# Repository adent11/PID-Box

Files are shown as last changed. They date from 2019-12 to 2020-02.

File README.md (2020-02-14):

# PID-Box Project <!--Temporary Title-->
The goal of the PID box project is to control the speed of a motor using a photinterrupter and PID.
# Project Timeline

|Week|Date| Planned Milestones|Actual Progress|
|----| -- | --- |---|
|1|10/28/19|Design mount for the motor, and the wheel|Designed mount for the motor, the wheel, and a simple t-slot wall|
|2|11/6/19|Design one wall assembly of motor, wheel, and <br/>photointerrupter|Made assembly with the motor, photointerrupter, LCD, some indicator LEDs, and the potentiometer|
|3|11/11/19|Finish designing the box, add in LCD, LED indicators,<br/> switches, battery pack, and potentiometer|Added switches, battery pack, and arduino; 3d printed motor mount|
|4|11/18/19|Add arduino, start assembling box|Started assembling, made fritzing diagram|
|5|12/2/19|Wire everything and get test code working|Mounted all but motor, due to its tendancy to attach crooked, started wiring|
|6|12/9/19|RPM code|Soldered wires to all of the components, wired all components, assembled box|
|7|1/6/20|PID code|Tested all components, started rpm code, |
|8|1/13/20|Non-PID code|Finished rpm code, started non-PID control code|
|9|1/22/20 |Wrap up loose ends|Finished non-PID control code, wrote PID code, started tuning PID variables|
|10|1/27/20|Delay compensation|Continued tuning PID constants, worked on problem with rpm accuracy|
|11|2/3/20|Delay compensation|Recut wheel, retuned PID constants|
|12|2/10/20|Delay compensation|Finalized code, finished readme|

# The Process
<details><summary><b>Pre-project Planning</b></summary>
<p>
I didn't do a lot of sketching or drawing out plans, so most of my project planning was done in either Solidworks or Arduino, starting with smaller assemblies or simple test codes to gain the understanding of how the project works. I did however spend a while before actually starting the project trying to understand how PID control works.
</p>
</details>

<details><summary><b>Week 1</b></summary>
<p>
  
* Designed mount for motor
* On the motor mount I had some trouble getting the screws to be in a place where I can screw all of them in, so I extended the part that attaches to the box
* Designed wheel 
<br/>
 <br/>
</p>
</details>

<details><summary><b>Week 2</b></summary>
<p>
  
* Made sub-assembly of the motor, wheel, and photointerrupter

<br/>


* Added a row of LEDs that will show the speed

<br/> 
</p>
</details>

<details><summary><b>Week 3</b></summary>
<p>
  
* Added in the rest of the components
* 3d printed the motor mount
* Made drawing of all PID box walls

<br/> 
</p>
</details>
  
<details><summary><b>Week 4</b></summary>
<p>
  
* Laser cut all walls
* Drilled to fix some holes that were the wrong size
* Recut a wall to have my name, labels for the switches, and some holes that should have been there
* Started making fritzing diagram
</p>
</details>

<details><summary><b>Week 5</b></summary>
<p>
  
* Got potentiometer and motor control working with test code
* Broke the wheel trying to put it on
* Made the hole in the wheel slightly wider and recut
* Having trouble attaching the motor and wheel straight
</p>
</details>
  
<details><summary><b>Week 6</b></summary>
<p>

* Soldered wires to all components
* Finished assembling box
* One problem that I faced this week was that all of my wiring had to fit into a relatively small space, so it was tedious and took a long time to wire <br/>
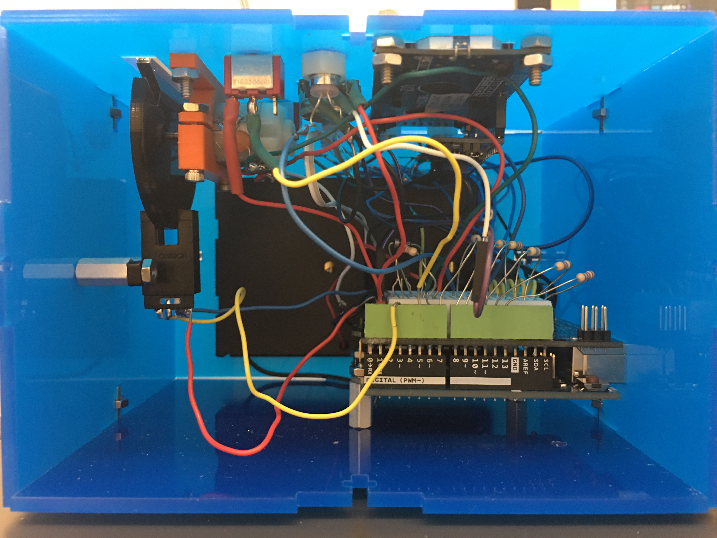
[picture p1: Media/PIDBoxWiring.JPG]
 <br/>
</p>
</details>

<details><summary><b>Week 7</b></summary>
<p>
  
* Tested all components
* I forgot to add a resistor to ground on the mode switch, so I had to solder that on
* Wrote rpm code

``` c++
int calcRPM()
{
  int rpm;
  rpm = interruptCount * (60000 / rpmCalcDelay) / 12; //Calculates rpm, interrupts times calculations per second divided by 
  return rpm;                                         //the number of interrupts per rotation
}
```
</p>
</details>

<details><summary><b>Week 8</b></summary>
<p>
  
* Finished and tested rpm code
* Started non-PID motor control code
</p>
</details>

<details><summary><b>Week 9</b></summary>
<p>
  
* Finished non-PID motor control code
* Finished PID control code
* Started tuning PID variables
</p>
</details>

<details><summary><b>Week 10</b></summary>
<p>
  
* Continued tuning PID constants
* Came across problem with RPM accuracy due to only having one hole cut in my wheel
</p>
</details>

<details><summary><b>Week 11</b></summary>
<p>
  
* Redesigned the wheel to have six holes instead of one for greater accuracy
* Retuned PID constants </br>
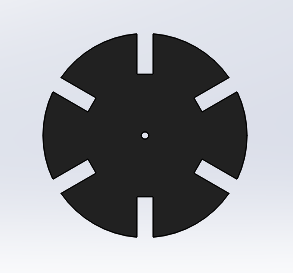
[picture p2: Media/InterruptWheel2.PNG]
 </br>
</p>
</details>

<details><summary><b>Week 12</b></summary>
<p>
  
* Finalized code
* Wrap up loose ends such as git
* Made this lovely readme
* Commented code
* Took videos, pictures, and screenshots
</p>
</details>
 
# The Finished Product

### Materials List
* LCD Screen
* LCD Backpack
* Photinterrupter
* 2 Switches
* 10k Potentiometer
* 6 AA Battery Pack
* DC Motor
* 8 220Ω Resistors
* 6 Red LEDs
* 1 Green LED
* Arduino Uno
* Prototyping Shield <br/>
* Box
* Wheel
* Motor Mount

### Wiring
The wiring for the PID Box was fairly straightforward, however having so many LEDs complicated my wiring slightly. I saved some space by soldering the ground legs of all of the LEDs together, and I used a breadboard in order to avoid having to solder resistors on to each LED. The first time I put it together, I forgot to ground the mode switch, so I had to reopen it and solder on the resistor. The only other complex wiring was that of the motor, but I already had that from the motor assignment, so all I had to do was copy it.
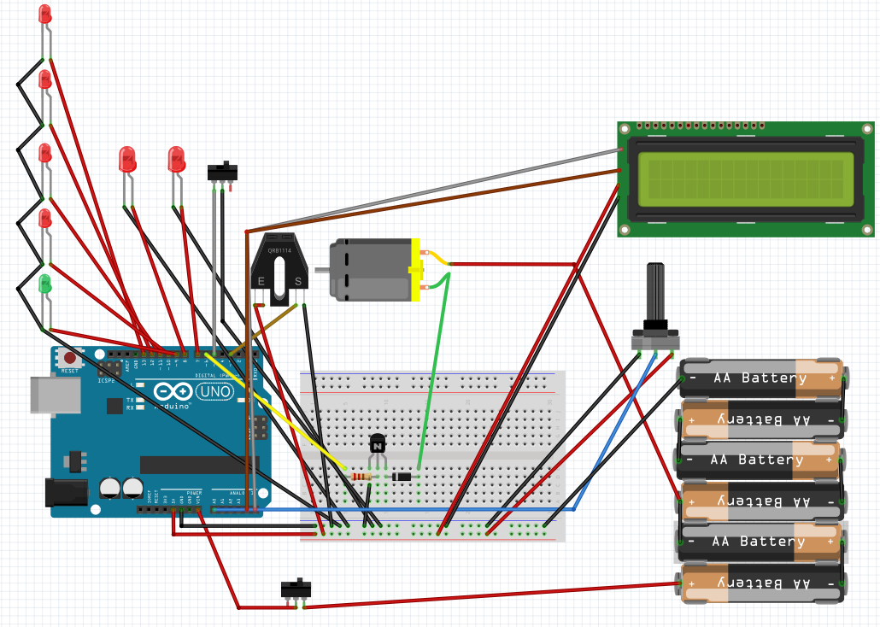
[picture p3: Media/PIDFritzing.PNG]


### The Box
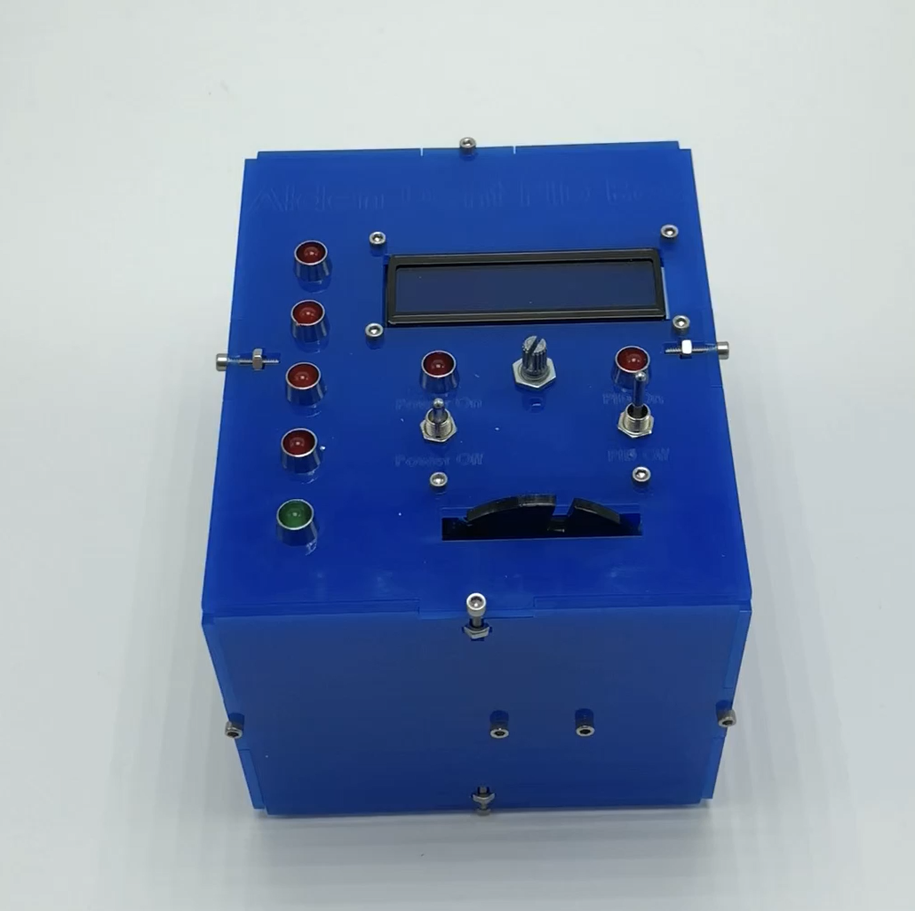
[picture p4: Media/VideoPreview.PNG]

<sup><a href="https://www.youtube.com/watch?v=RjP5sMNfZZY&feature=youtu.be" target="_blank">The PID Box in action</a></sup>

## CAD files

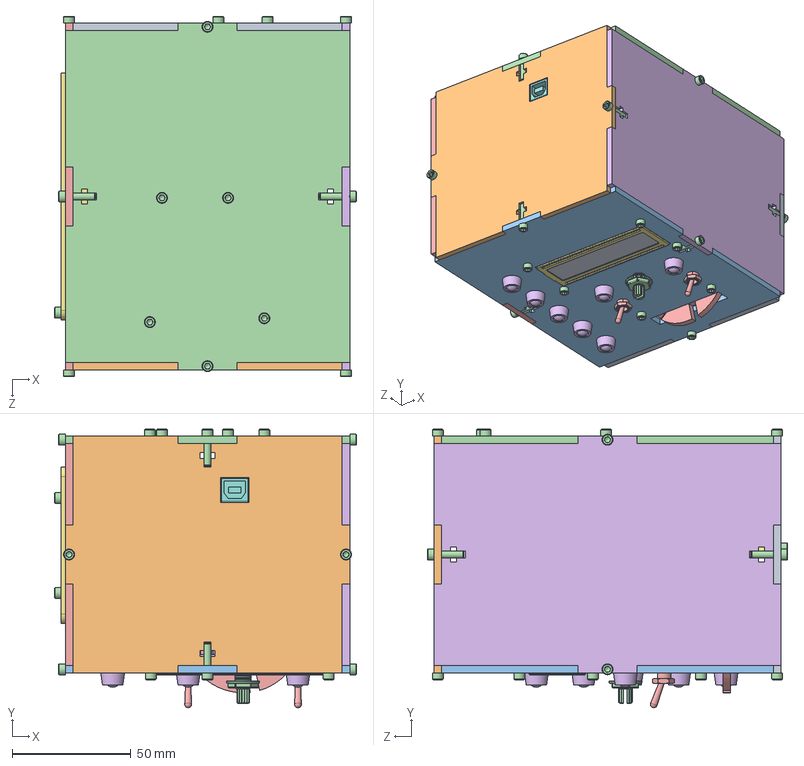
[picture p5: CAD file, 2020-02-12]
Solidworks/PIDBoxAssem.SLDASM
127.4 x 117.5 x 152.0 mm
PIDBoxFrontWall
PIDBoxBackWall
PIDBoxTopWall
PIDBoxBottomWall
PIDBoxLeftWall
PIDBoxRightWall
BatteryPack
ArduinoUno
EE-SX672WR
MotorMount
DCmotor-Size130
socket head cap screw_ai x 30
InterruptWheel
LCD_PCB
metal_casing
LCDbacklight
LCD
conductors x 2
LCD Backpack
Panel Mount 10k Potentiometer
Panel Mount SPDT x 2
Panel Mount LED x 7
25x.5 Aluminum Hex Female Female Standoff x 6

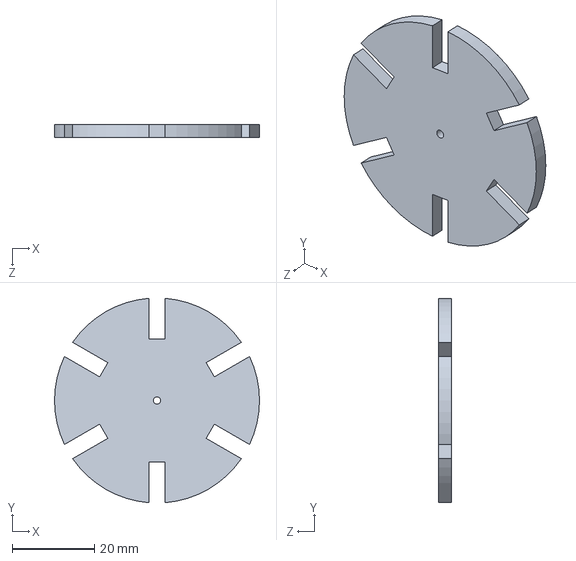
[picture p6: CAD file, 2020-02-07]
Solidworks/InterruptWheel.SLDPRT
50.0 x 49.8 x 3.17 mm

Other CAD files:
Solidworks/MotorAssem.SLDASM
Solidworks/PIDBoxTopWall.SLDPRT
Solidworks/InterruptWheelCut.SLDDRW
Solidworks/InterruptWheelReCut.SLDDRW
Solidworks/PIDBoxTopWallReCut.SLDDRW

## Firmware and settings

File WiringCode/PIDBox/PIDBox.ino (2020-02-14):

//PIDBox.ino
//Alden Dent
//Main PID Box Code

#include <LiquidCrystal_I2C.h>
#include <Wire.h>

LiquidCrystal_I2C lcd(0x3F, 16, 2); // set the LCD address to 0x27 for a 16 chars and 2 line display.
// If 0x27 doesn't work, try 0x3F.

// rpm varibles
volatile int interruptCount = 0;  //How many times the wheel passes throught the interrupter
const int rpmCalcDelay = 166;  //Delay between calculations of rpm
long oldmillis = 0; //Old time value so the timer works

// motor control variables
const int interruptPin = 3;
const int motorPin = 6;
int actualSpeed = 0;  //Speed in RPM mapped from 0-100
int setPoint = 0; //How fast you want it to go
int motorPower = 0; //The amout of power sent to the motor
int error;  //Difference between set and actual speed
int adjustment; //proportional control adjustment

//PID variables
double kP = 6; //PID constant
double kI = .01; //PID constant
double kD = 0.0000; //PID constant
int oldError; //Previous error, used to find
float Derivative, Drive, Integral;  //PID values

// user control pins
const int modeSwitch = 5;
const int potPin = A0; //Speed potentiometer pin
int initialized = 0;  //Makes it so the message for control type ony appears once

//LED indicator pins
const int pidLed = 7; //Power indacator pin
const int pwrLed = 8;  //Mode indacator pin
const int ledBlink = 9; //Blinking led pin
const int led1 = 10;  //Speed led pin
const int led2 = 11;  //Speed led pin
const int led3 = 12;  //Speed led pin
const int led4 = 13;  //Speed led pin
bool ledblink = false;  //Blinking led state
int ledStartupDelay = 70; //Delay between blinks in initializing led show



void setup()
{
  Serial.begin(9600);

  lcd.init();   //Setup for LCD
  lcd.backlight();
  lcd.begin(16, 2);
  lcd.clear();

  pinMode(motorPin, OUTPUT);  //Sets modes for all pins
  pinMode(modeSwitch, INPUT);
  pinMode(pidLed, OUTPUT);
  pinMode(pwrLed, OUTPUT);
  digitalWrite(pwrLed, HIGH);
  pinMode(led1, OUTPUT);
  pinMode(led2, OUTPUT);
  pinMode(led3, OUTPUT);
  pinMode(led4, OUTPUT);
  pinMode(ledBlink, OUTPUT);
  pinMode(interruptPin, INPUT_PULLUP);  //Make sure you use INPUT_PULLUP for the interrupt pin

  attachInterrupt(digitalPinToInterrupt(interruptPin), count, CHANGE);
  initialized = digitalRead(modeSwitch);  //Makes sure it knows which mode it is in
  initSequence(); //Fancy leds

}




void loop()
{

  setPoint = map(analogRead(potPin), 0, 1023, 0, 100);  //Sets setPoint to mapped potentiometer value

  lcd.setCursor(0, 0);
  lcd.print("Setpoint: ");
  lcd.print(setPoint);
  lcd.print("       "); //Extra space so no messages overlap
  lcd.setCursor(0, 1);
  lcd.print("Speed: ");
  lcd.print(actualSpeed);
  lcd.print("       "); //Extra space so no messages overlap
  setLeds();  //Sets LEDs that show speed




  if (millis() >= oldmillis + rpmCalcDelay) {
    detachInterrupt(digitalPinToInterrupt(interruptPin)); //Detaches the interrupt so it doesn't mess up the math
    actualSpeed = map(calcRPM(), 0, 5000, 0, 100);  //Maps rpm from 0 to 100

    //No PID loop
    if (digitalRead(modeSwitch) == LOW) {
      if (initialized == 0) { //Initialization sequence
        digitalWrite(pidLed, LOW);  //LED shows which mode
        lcd.clear();
        lcd.print("PID OFF                       ");  //LCD prints the mode
        initialized = 1;  //Switches so it only initializes once
        delay(800); //Delay so user can read the message
      }

      analogWrite(motorPin, map(analogRead(potPin), 0, 1023, 0, 248)); //Sets motor power to a mapped potentiometer value

    }


    else  {
      //PID loop
      if (initialized == 1) { //Initialization sequence
        digitalWrite(pidLed, HIGH); //LED shows which mode
        lcd.clear();
        lcd.print("PID ON                     ");  //LCD prints the mode
        initialized = 0;  //Switches so it only initializes once
        delay(800); //Delay so user can read the message
      }

      error = setPoint - actualSpeed; //PID math
      Integral = constrain((Integral + (error * rpmCalcDelay)), -10000, 10000); //PID math
      Derivative = (error - oldError) / rpmCalcDelay; //PID math
      motorPower = (error * kP) + (Integral * kI) + (Derivative * kD);  //PID math
      oldError = error;

      analogWrite(motorPin, constrain(motorPower + map(analogRead(potPin), 0, 1023, 0, 150), 0, 255));  //Sets motor power to PID correction power

    }
    interruptCount = 0; //Resets interrupt counter
    oldmillis = millis(); //Resets the timer

    Serial.print(setPoint); //Shows setpoint and speed as two lines on serial plotter
    Serial.print(",");  //Shows setpoint and speed as two lines on serial plotter
    Serial.println(actualSpeed);  //Shows setpoint and speed as two lines on serial plotter

    attachInterrupt(digitalPinToInterrupt(interruptPin), count, CHANGE);  //Reattaches the interrupt
  }

}

void count()  //Interrupt loop
{
  interruptCount = interruptCount + 1;  //Adds one to interrupt count
  ledblink = !ledblink; //Switches the state of the blinking led
  digitalWrite(ledBlink, ledblink); //Turns led on or off
}


int calcRPM()
{
  int rpm;
  rpm = interruptCount * (60000 / rpmCalcDelay) / 12; //Calculates rpm, interrupts times calculations per second divided by the number of interrupts per rotation
  return rpm;
}

void setLeds()  //Sets speed LEDs
{
  if (actualSpeed > 0) {  //If speed 1-24 one LED is on
    digitalWrite(led1, HIGH);
    digitalWrite(led2, LOW);
    digitalWrite(led3, LOW);
    digitalWrite(led4, LOW);
  }

  if (actualSpeed > 25) { //If speed is 25-49 two LEDs are on
    digitalWrite(led1, HIGH);
    digitalWrite(led2, HIGH);
    digitalWrite(led3, LOW);
    digitalWrite(led4, LOW);
  }

  if (actualSpeed > 50) { //If speed is 50-74 three LEDs are on
    digitalWrite(led1, HIGH);
    digitalWrite(led2, HIGH);
    digitalWrite(led3, HIGH);
    digitalWrite(led4, LOW);
  }

  if (actualSpeed > 75) { //If speed is above 75 all four LEDs are on
    digitalWrite(led1, HIGH);
    digitalWrite(led2, HIGH);
    digitalWrite(led3, HIGH);
    digitalWrite(led4, HIGH);
  }
  if (actualSpeed == 0) { //If speed is 0 no LEDs are on
    digitalWrite(led1, LOW);
    digitalWrite(led2, LOW);
    digitalWrite(led3, LOW);
    digitalWrite(led4, LOW);
  }
}


void initSequence() { //Types out my name and PID box and does fancy LED stuff
  lcd.print("A");
  delay(50);
  lcd.print("l");
  delay(50);
  lcd.print("d");
  delay(50);
  lcd.print("e");
  delay(50);
  lcd.print("n");
  delay(50);
  lcd.print("  ");
  lcd.print("D");
  delay(50);
  lcd.print("e");
  delay(50);
  lcd.print("n");
  delay(50);
  lcd.print("t");
  lcd.setCursor(0, 1);  //Puts the cursor on the next line
  lcd.print("P");
  delay(50);
  lcd.print("I");
  delay(50);
  lcd.print("D");
  delay(50);
  lcd.print("  B");
  delay(50);
  lcd.print("o");
  delay(50);
  lcd.print("x");
  digitalWrite(ledBlink, HIGH); //Turns LEDs on and off in pretty patterns
  digitalWrite(led1, HIGH);
  delay(ledStartupDelay);
  digitalWrite(ledBlink, LOW);
  digitalWrite(led2, HIGH);
  delay(ledStartupDelay);
  digitalWrite(led1, LOW);
  digitalWrite(led3, HIGH);
  delay(ledStartupDelay);
  digitalWrite(led2, LOW);
  digitalWrite(led4, HIGH);
  delay(ledStartupDelay);
  digitalWrite(led3, LOW);
  delay(ledStartupDelay);
  digitalWrite(led4, LOW);
  delay(ledStartupDelay);
  digitalWrite(ledBlink, HIGH);
  digitalWrite(led1, HIGH);
  delay(ledStartupDelay);
  digitalWrite(ledBlink, LOW);
  digitalWrite(led2, HIGH);
  delay(ledStartupDelay);
  digitalWrite(led1, LOW);
  digitalWrite(led3, HIGH);
  delay(ledStartupDelay);
  digitalWrite(led2, LOW);
  digitalWrite(led4, HIGH);
  delay(ledStartupDelay);
  digitalWrite(led3, LOW);
  delay(ledStartupDelay);
  digitalWrite(led4, LOW);
  delay(ledStartupDelay);
  digitalWrite(ledBlink, HIGH);
  digitalWrite(led1, HIGH);
  digitalWrite(led2, HIGH);
  digitalWrite(led3, HIGH);
  digitalWrite(led4, HIGH);
  delay(300);
  digitalWrite(ledBlink, LOW);
  digitalWrite(led1, LOW);
  digitalWrite(led2, LOW);
  digitalWrite(led3, LOW);
  digitalWrite(led4, LOW);
  delay(300);
  digitalWrite(ledBlink, HIGH);
  digitalWrite(led1, HIGH);
  digitalWrite(led2, HIGH);
  digitalWrite(led3, HIGH);
  digitalWrite(led4, HIGH);
  delay(300);
  digitalWrite(ledBlink, LOW);
  digitalWrite(led1, LOW);
  digitalWrite(led2, LOW);
  digitalWrite(led3, LOW);
  digitalWrite(led4, LOW);
  delay(1000);
  lcd.clear();
  delay(1000);
}

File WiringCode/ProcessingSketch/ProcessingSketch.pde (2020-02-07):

import processing.serial.*;

  Serial myPort;        // The serial port
  int xPos = 1;         // horizontal position of the graph
  float inByte = 0;

  void setup () {
    // set the window size:
    size(800, 600);

    // List all the available serial ports
    // if using Processing 2.1 or later, use Serial.printArray()
    println(Serial.list());

    // I know that the first port in the serial list on my Mac is always my
    // Arduino, so I open Serial.list()[0].
    // Open whatever port is the one you're using.
    myPort = new Serial(this, Serial.list()[1], 9600);

    // don't generate a serialEvent() unless you get a newline character:
    myPort.bufferUntil('\n');

    // set initial background:
    background(0);
  }

  void draw () {
    // draw the line:
    stroke(127, 34, 255);
    line(xPos, height, xPos, height - inByte);

    // at the edge of the screen, go back to the beginning:
    if (xPos >= width) {
      xPos = 0;
      background(0);
    } else {
      // increment the horizontal position:
      xPos++;
    }
  }

  void serialEvent (Serial myPort) {
    // get the ASCII string:
    String inString = myPort.readStringUntil('\n');

    if (inString != null) {
      // trim off any whitespace:
      inString = trim(inString);
      // convert to an int and map to the screen height:
      inByte = float(inString);
      println(inByte);
      inByte = map(inByte, 0, 1023, 0, height);
    }
  }



/* Max/MSP v5 patch for this example

 ----------begin_max5_patcher----------
1591.3oc0YszbaaCD9r7uBL5RalQUAO3CvdyS5zVenWZxs5NcfHgjPCIfJIT
RTxj+6AOHkoTDooroUs0AQPR73a+1cwtK3WtZxzEpOwqlB9YveAlL4KWMYh6
Q1GLo99ISKXeJMmU451zTUQAWpmNy+NM+SZ2y+sR1l02JuU9t0hJvFlNcMPy
dOuBv.U5Rgb0LPpRpYBooM3529latArTUVvzZdFPtsXAuDrrTU.f.sBffXxL
vGE50lIHkUVJXq3fRtdaoDvjYfbgjujaFJSCzq4.tLaN.bi1tJefWpqbO0uz
1IjIABoluxrJ1guxh2JfPO2B5zRNyBCLDFcqbwNvuv9fHCb8bvevyyEU2JKT
YhkBSWPAfq2TZ6YhqmuMUo0feUn+rYpY4YtY+cFw3lUJdCMYAapZqzwUHX8S
crjAd+SIOU6UBAwIygy.Q1+HAA1KH6EveWOFQlitUK92ehfal9kFhUxJ3tWc
sgpxadigWExbt1o7Ps5dk3yttivyg20W0VcSmg1G90qtx92rAZbH4ez.ruy1
nhmaDPidE07J+5n2sg6E6oKXxUSmc20o6E3SPRDbrkXnPGUYE.i5nCNB9TxQ
jG.G0kCTZtH88f07Rt0ZMMWUw8VvbKVAaTk6GyoraPdZff7rQTejBN54lgyv
HE0Ft7AvIvvgvIwO23jBdUkYOuSvIFSiNcjFhiSsUBwsUCh1AgfNSBAeNDBZ
DIDqY.f8.YjfjV1HAn9XDTxyNFYatVTkKx3kcK9GraZpI5jv7GOx+Z37Xh82
LSKHIDmDXaESoXRngIZQDKVkpxUkMCyXCQhcCK1z.G457gi3TzMz4RFD515F
G3bIQQwcP3SOF0zlkGhiCBQ1kOHHFFlXaEBQIQnCwv9QF1LxPZ.A4jR5cyQs
vbvHMJsLll01We+rE2LazX6zYmCraRrsPFwKg1ANBZFY.IAihr8Ox.aH0oAL
hB8nQVw0FSJiZeunOykbT6t3r.NP8.iL+bnwNiXuVMNJH9H9YCm89CFXPBER
bz422p8.O4dg6kRxdyjDqRwMIHTbT3QFLskxJ8tbmQK4tm0XGeZWF7wKKtYY
aTAF.XPNFaaQBinQMJ4QLF0aNHF0JtYuHSxoUZfZY6.UU2ejJTb8lQw8Fo5k
Rv6e2PI+fOM71o2ecY1VgTYdCSxxUqLokuYq9jYJi6lxPgD2NIPePLB0mwbG
YA9Rgxdiu1k5xiLlSU6JVnx6wzg3sYHwTesB8Z5D7RiGZpXyvDNJY.DQX3.H
hvmcUN4bP1yCkhpTle2P37jtBsKrLWcMScEmltOPv22ZfAqQAdKr9HzATQwZ
q18PrUGt6Tst2XMCRUfGuhXs6ccn23YloomMqcTiC5iMGPsHsHRWhWFlaenV
XcqwgCQiGGJzptyS2ZMODBz6fGza0bzmXBj7+DA94bvpR01MffAlueO7HwcI
pWCwmzJdvi9ILgflLAFmyXB6O7ML0YbD26lenmcGxjVsZUN+A6pUK7AtTrPg
M+eRYG0qD9j4I7eEbco8Xh6WcO.or9XDC6UCiewbXHkh6xm5LiPEkzpJDRTu
mEB44Fgz4NCtJvX.SM1vo2SlTCZGAe7GZu6ahdRyzFOhYZ+mbVVSYptBw.K1
tboIkatIA7c1cTKD1u.honLYV04VkluHsXe0szv9pQCE9Ro3jaVB1o15pz2X
zYoBvO5KXCAe0LCYJybE8ZODf4fV8t9qW0zYxq.YJfTosj1bv0xc.SaC0+AV
9V9L.KKyV3SyTcRtmzi6rO.O16USvts4B5xe9EymDvebK0eMfW6+NIsNlE2m
eqRyJ0utRq13+RjmqYKN1e.4d61jjdsauXe3.2p6jgi9hsNIv97CoyJ01xzl
c3ZhUCtSHx3UZgjoEJYqNY+hYs5zZQVFW19L3JDYaTlMLqAAt1G2yXlnFg9a
53L1FJVcv.cOX0dh7mCVGCLce7GFcQwDdH5Ta3nyAS0pQbHxegr+tGIZORgM
RnMj5vGl1Fs16drnk7Tf1XOLgv1n0d2iEsCxR.eQsNOZ4FGF7whofgfI3kES
1kCeOX5L2rifbdu0A9ae2X.V33B1Z+.Bj1FrP5iFrCYCG5EUWSG.hhunHJd.
HJ5hhnng3h9HPj4lud02.1bxGw.
-----------end_max5_patcher-----------

*/

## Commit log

2019-12-06 Make fritzing, cut and recut interrupt wheel
    [InterruptWheel.SLDPRT, InterruptWheelCut.SLDDRW, InterruptWheelReCut.SLDDRW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]
2019-12-10 Add PID box code with pins defined
2019-12-13 Add photo of wiring
2020-01-13 add test files and edit proto pid code
2020-02-07 Final code maybe
    [InterruptWheel.SLDPRT, InterruptWheelCut.SLDDRW]
2020-02-07 Add screenshot of new wheel
2020-02-12 Add fritzing diagram screenshot
    [PIDBoxAssem.SLDASM, PIDFritzing.fzz]
2020-02-13 Take another screenshot of fritzing diagram
    [PIDFritzing.fzz]
2020-02-14 Clamp integral
